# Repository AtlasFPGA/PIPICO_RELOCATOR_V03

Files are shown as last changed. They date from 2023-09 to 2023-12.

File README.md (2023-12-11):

# PIPICO_RELOCATOR_V0

Group ATLAS in Telegram: https://t.me/INICIATIVAATLAS

Agregadas salidas para poder usar módulos I2S Texas Instruments PCM5102A

Visionado del ajuste de pares diferenciales:
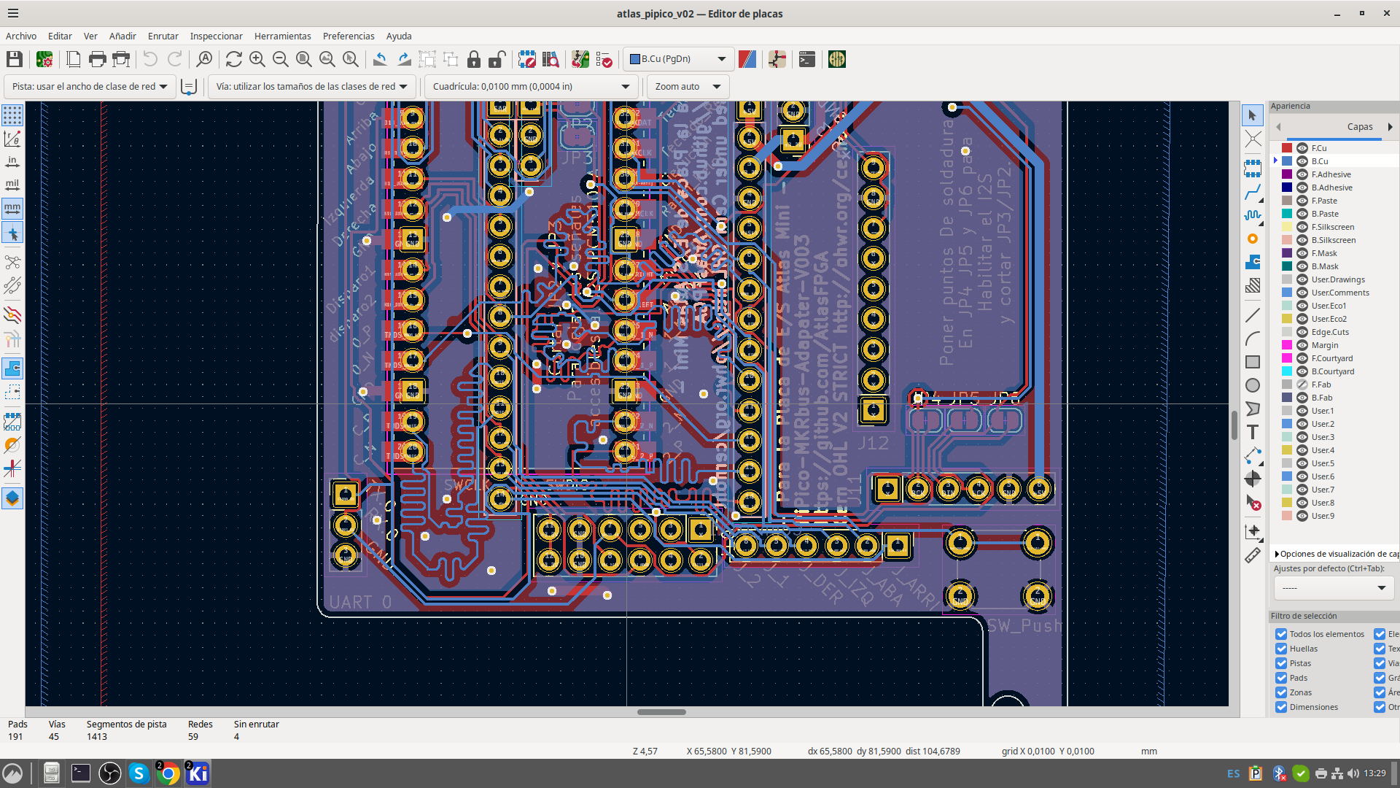
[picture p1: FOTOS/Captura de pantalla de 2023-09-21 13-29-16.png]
ajustar distancia pares diferenciales


Modificaciones sobre el recolocador PI-PICO que ha realizado Carlos Palmero, con el objetivo de que quede más centrada la placa en la versión de coste reducido de ATLAS, es decir "¡la roja!"
Marcando el uso de un módulo I2S de bajo costo como es el Texas Instruments PCM5102A, y posiblemente en el futuro un micrófono capacitivo I2S.

El proyecto pone a disposición los ficheros necesarios del paquete de desarrollo KICAD.
Se han calculado todas las pistas de los pares diferenciales y en este modelo se han ajustado por completo, desde la medición de la longitud de las pistas en la placa "¡la roja!" para que la distancia de los pares coincidan en todas las pistas.

Vistas en 3D del montaje, se puede ver que he dejado el orificio para ajustar la posición de la placa, y que se ha recortado la zona del bus de 40 pines.

### Vista 1 Tridimensional:
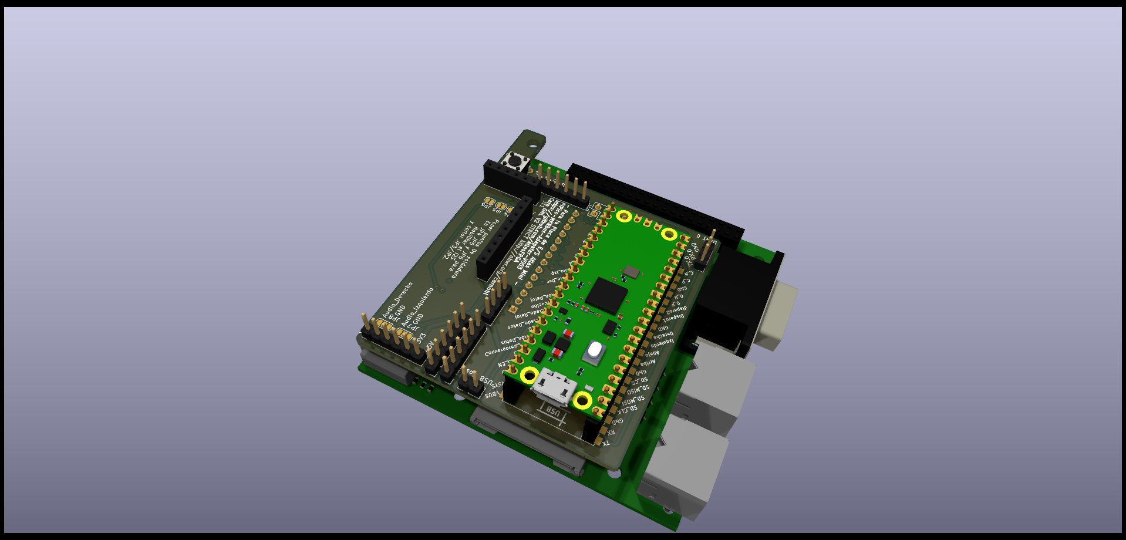
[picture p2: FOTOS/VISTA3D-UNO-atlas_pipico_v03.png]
Vista tridimensional 1


### Vista 2 Tridimensional:
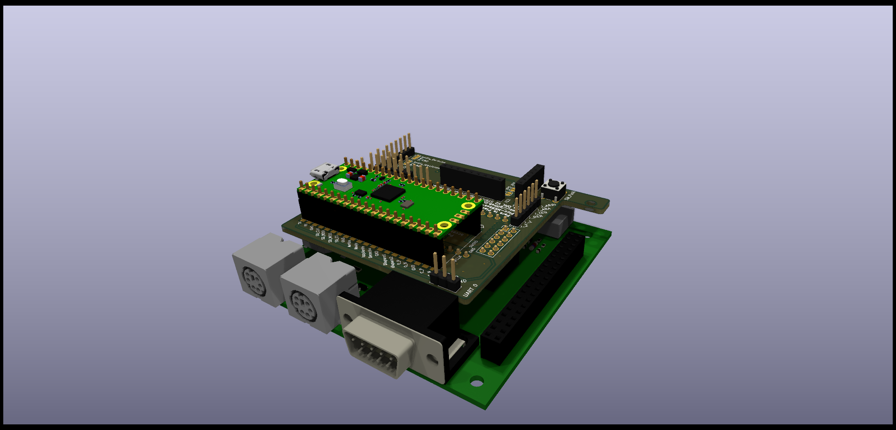
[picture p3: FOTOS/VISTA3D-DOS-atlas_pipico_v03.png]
Vista tridimensional 2


### Vista 3 Tridimensional:
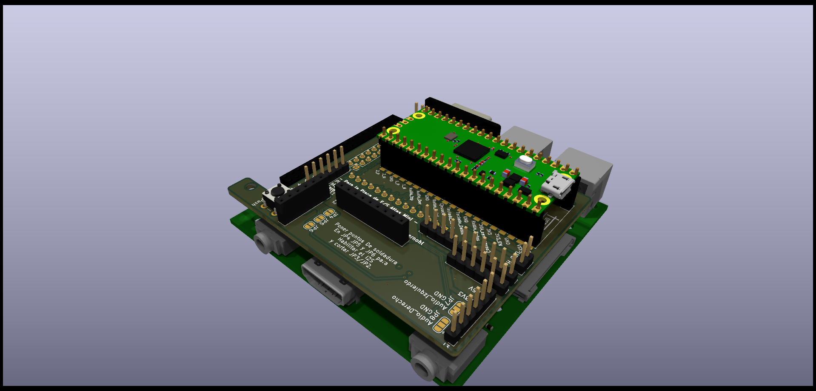
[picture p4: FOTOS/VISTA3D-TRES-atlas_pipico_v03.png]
Vista tridimensional 3


Licencia:
CERN OHL V2 STRICT
https://ohwr.org/cern_ohl_s_v2.txt

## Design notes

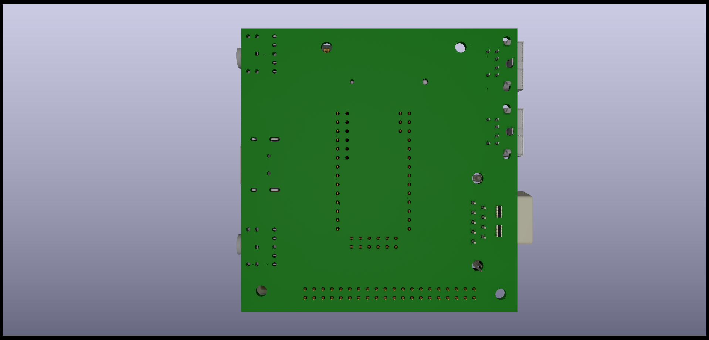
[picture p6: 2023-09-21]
FOTOS/Inferior-atlas_pipico_v03.png

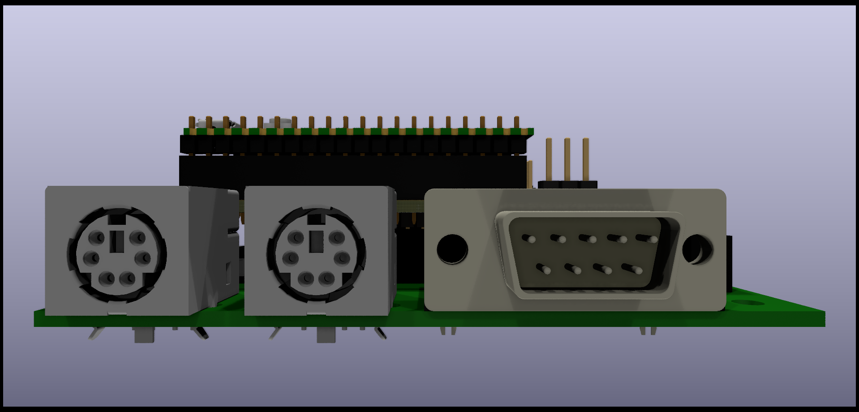
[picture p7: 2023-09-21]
FOTOS/Izquierda-atlas_pipico_v03.png

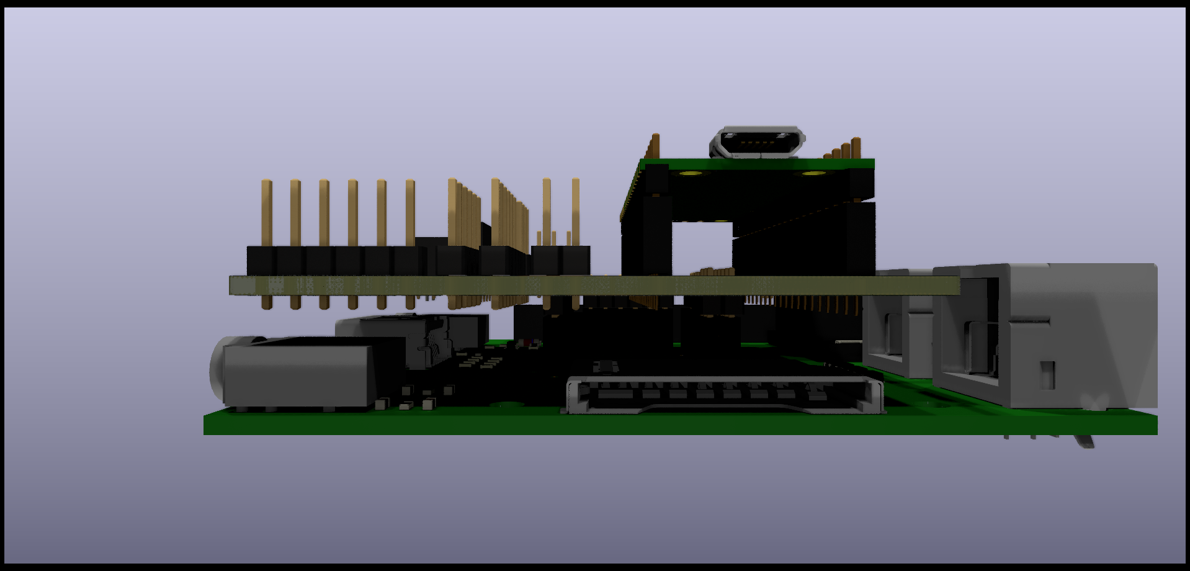
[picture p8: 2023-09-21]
FOTOS/Trasera-atlas_pipico_v03.png

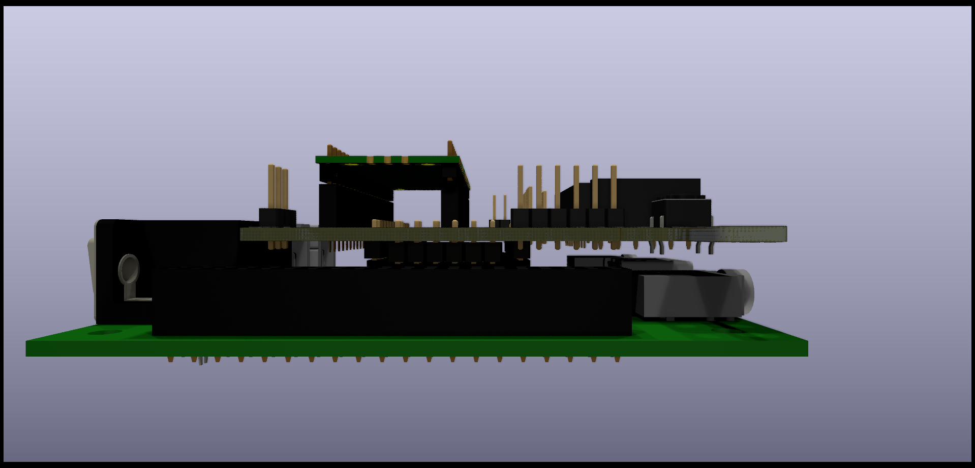
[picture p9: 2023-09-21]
FOTOS/Frontal-atlas_pipico_v03.png

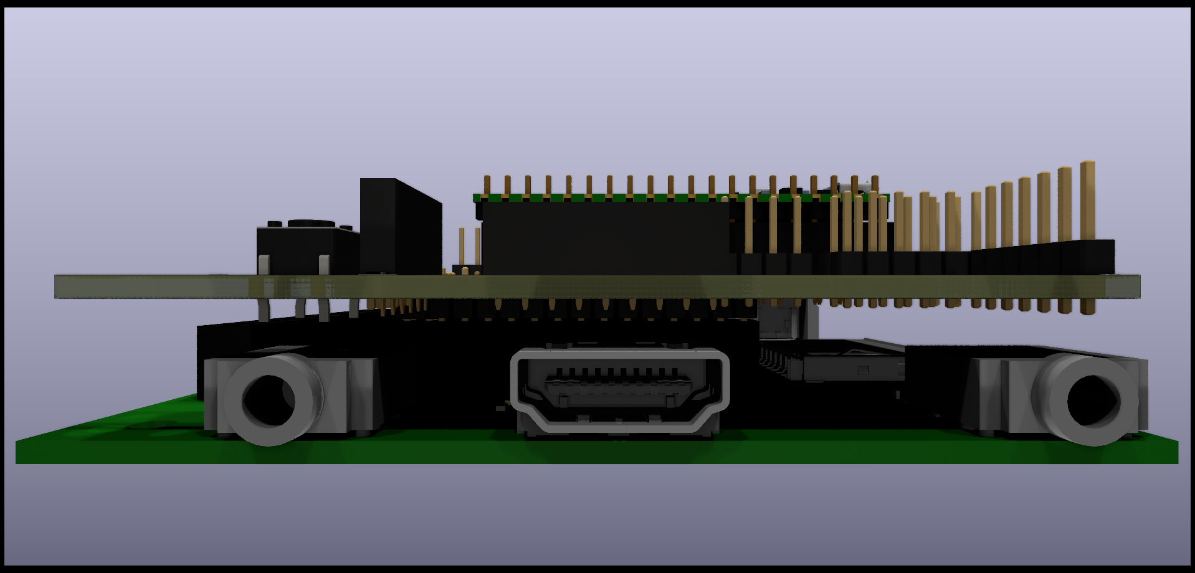
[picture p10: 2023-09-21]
FOTOS/Derecha-atlas_pipico_v03.png

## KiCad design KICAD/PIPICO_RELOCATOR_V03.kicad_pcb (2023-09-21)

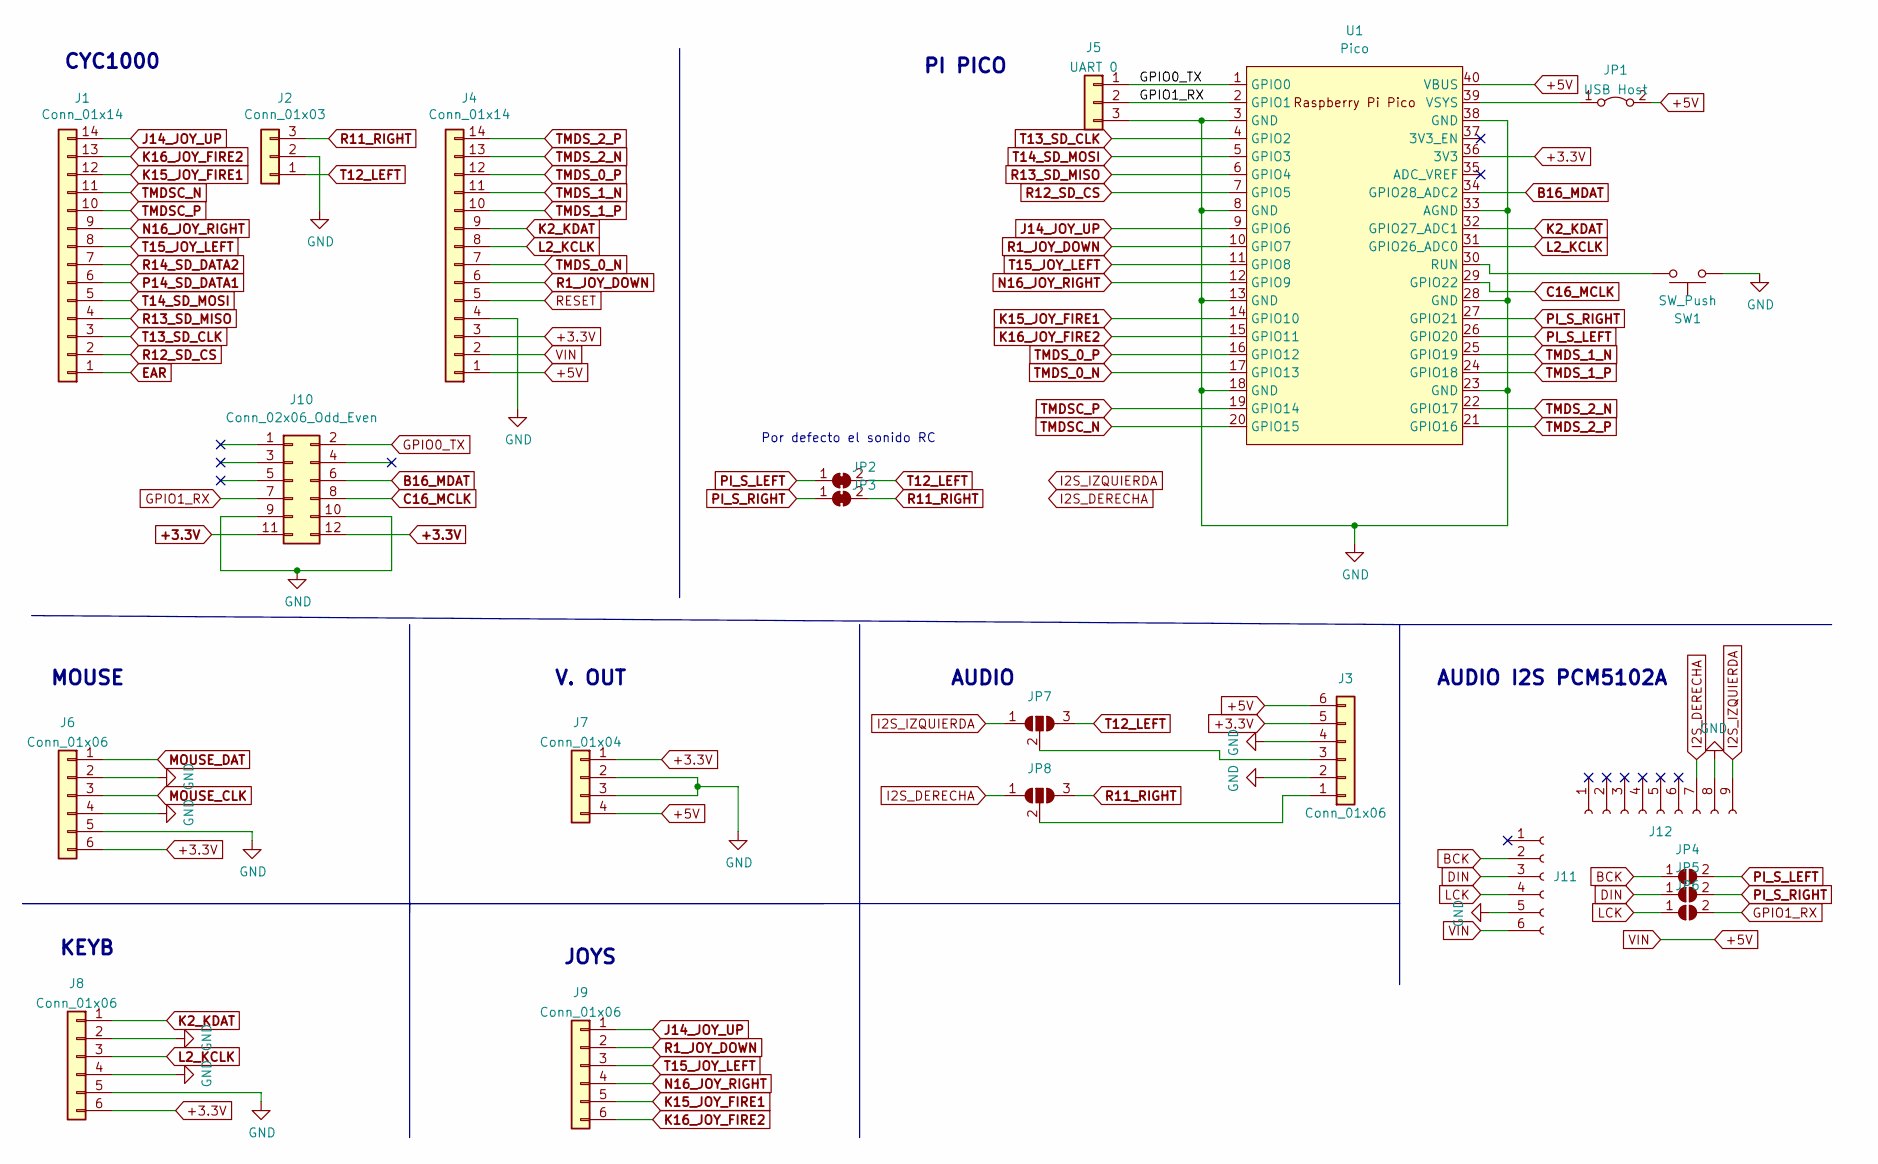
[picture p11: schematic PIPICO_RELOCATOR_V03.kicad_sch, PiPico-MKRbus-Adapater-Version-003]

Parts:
J1, J4: Conn_01x14; PinHeader_1x14_P2.54mm_Vertical
J2: Conn_01x03; PinHeader_1x03_P2.54mm_Vertical
J3, J6, J8, J9: Conn_01x06; PinHeader_1x06_P2.54mm_Vertical
J5: UART 0; PinHeader_1x03_P2.54mm_Vertical
J7: Conn_01x04; PinHeader_1x04_P2.54mm_Vertical
J10: Conn_02x06_Odd_Even; PinHeader_2x06_P2.54mm_Vertical
J11: Conn_01x06_Female; PinSocket_1x06_P2.54mm_Vertical
J12: Conn_01x09_Female; PinSocket_1x09_P2.54mm_Vertical
JP1: USB Host; PinHeader_1x02_P2.54mm_Vertical
JP2, JP3: SolderJumper_2_Bridged; SolderJumper-2_P1.3mm_Bridged2Bar_RoundedPad1.0x1.5mm
JP4, JP5, JP6: SolderJumper_2_Open; SolderJumper-2_P1.3mm_Open_RoundedPad1.0x1.5mm
JP7, JP8: SolderJumper_3_Open; SolderJumper-3_P1.3mm_Open_RoundedPad1.0x1.5mm
SW1: SW_Push; SW_PUSH_6mm
U1: Pico; RPi_Pico_SMD_TH

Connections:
+3.3V: J3.5, J4.3, J6.6, J7.1, J8.6, J10.11, J10.12, U1.36 (3V3)
+5V: J3.6, J4.1, J4.2, J7.4, J11.6, JP1.2 (B), U1.40 (VBUS)
B16_MDAT: J10.6, U1.34 (GPIO28_ADC2)
BCK: J11.2, JP4.1 (A)
C16_MCLK: J10.8, U1.29 (GPIO22)
DIN: J11.3, JP5.1 (A)
EAR: J1.1
GND: J2.2, J3.2, J3.4, J4.4, J5.3, J6.2, J6.4, J6.5, J7.2, J7.3, J8.2, J8.4, J8.5, J10.9, J10.10, J11.5, J12.8, SW1.2, U1.3 (GND), U1.8 (GND), U1.13 (GND), U1.18 (GND), U1.23 (GND), U1.28 (GND), U1.33 (AGND), U1.38 (GND)
GPIO0_TX: J5.1, J10.2, U1.1 (GPIO0)
GPIO1_RX: J5.2, J10.7, JP6.2 (B), U1.2 (GPIO1)
I2S_DERECHA: J12.7, JP8.1 (A)
I2S_IZQUIERDA: J12.9, JP7.1 (A)
J14_JOY_UP: J1.14, J9.1, U1.9 (GPIO6)
K2_KDAT: J4.9, J8.1, U1.32 (GPIO27_ADC1)
K15_JOY_FIRE1: J1.12, J9.5, U1.14 (GPIO10)
K16_JOY_FIRE2: J1.13, J9.6, U1.15 (GPIO11)
L2_KCLK: J4.8, J8.3, U1.31 (GPIO26_ADC0)
LCK: J11.4, JP6.1 (A)
MOUSE_CLK: J6.3
MOUSE_DAT: J6.1
N16_JOY_RIGHT: J1.9, J9.4, U1.12 (GPIO9)
unnamed: J3.1, JP8.2 (C)
unnamed: J3.3, JP7.2 (C)
unnamed: JP1.1 (A), U1.39 (VSYS)
unnamed: SW1.1, U1.30 (RUN)
P14_SD_DATA1: J1.6
PI_S_LEFT: JP2.1 (A), JP4.2 (B), U1.26 (GPIO20)
PI_S_RIGHT: JP3.1 (A), JP5.2 (B), U1.27 (GPIO21)
R1_JOY_DOWN: J4.6, J9.2, U1.10 (GPIO7)
R11_RIGHT: J2.3, JP3.2 (B), JP8.3 (B)
R12_SD_CS: J1.2, U1.7 (GPIO5)
R13_SD_MISO: J1.4, U1.6 (GPIO4)
R14_SD_DATA2: J1.7
RESET: J4.5
T12_LEFT: J2.1, JP2.2 (B), JP7.3 (B)
T13_SD_CLK: J1.3, U1.4 (GPIO2)
T14_SD_MOSI: J1.5, U1.5 (GPIO3)
T15_JOY_LEFT: J1.8, J9.3, U1.11 (GPIO8)
TMDSC_N: J1.11, U1.20 (GPIO15)
TMDSC_P: J1.10, U1.19 (GPIO14)
TMDS_0_N: J4.7, U1.17 (GPIO13)
TMDS_0_P: J4.12, U1.16 (GPIO12)
TMDS_1_N: J4.11, U1.25 (GPIO19)
TMDS_1_P: J4.10, U1.24 (GPIO18)
TMDS_2_N: J4.13, U1.22 (GPIO17)
TMDS_2_P: J4.14, U1.21 (GPIO16)

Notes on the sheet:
MOUSE
CYC1000
AUDIO
KEYB
JOYS
PI PICO
Por defecto el sonido RC
AUDIO I2S PCM5102A
V. OUT

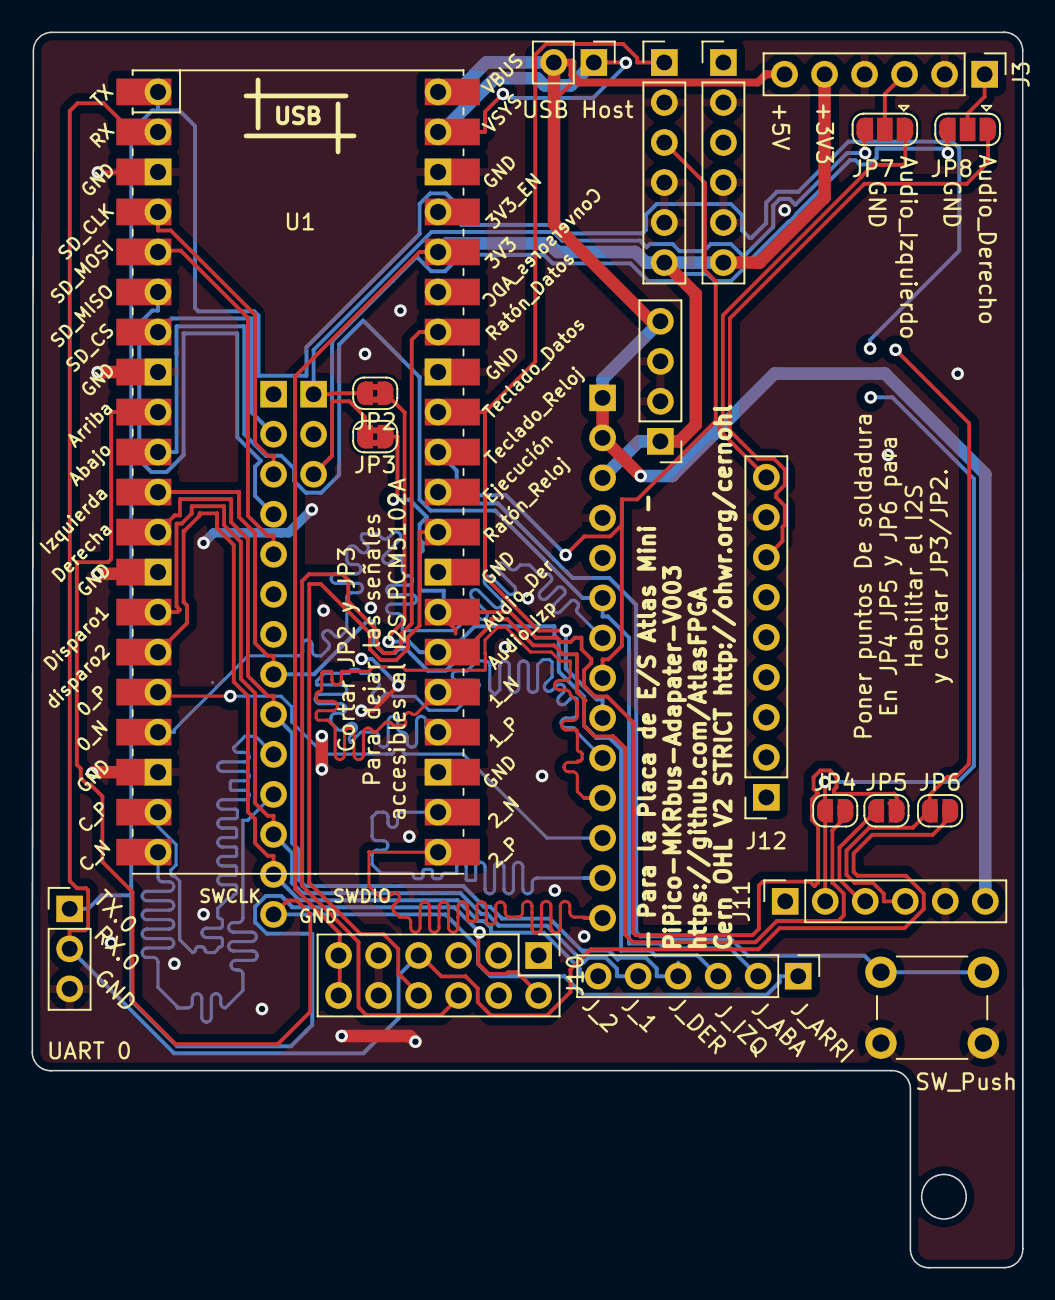
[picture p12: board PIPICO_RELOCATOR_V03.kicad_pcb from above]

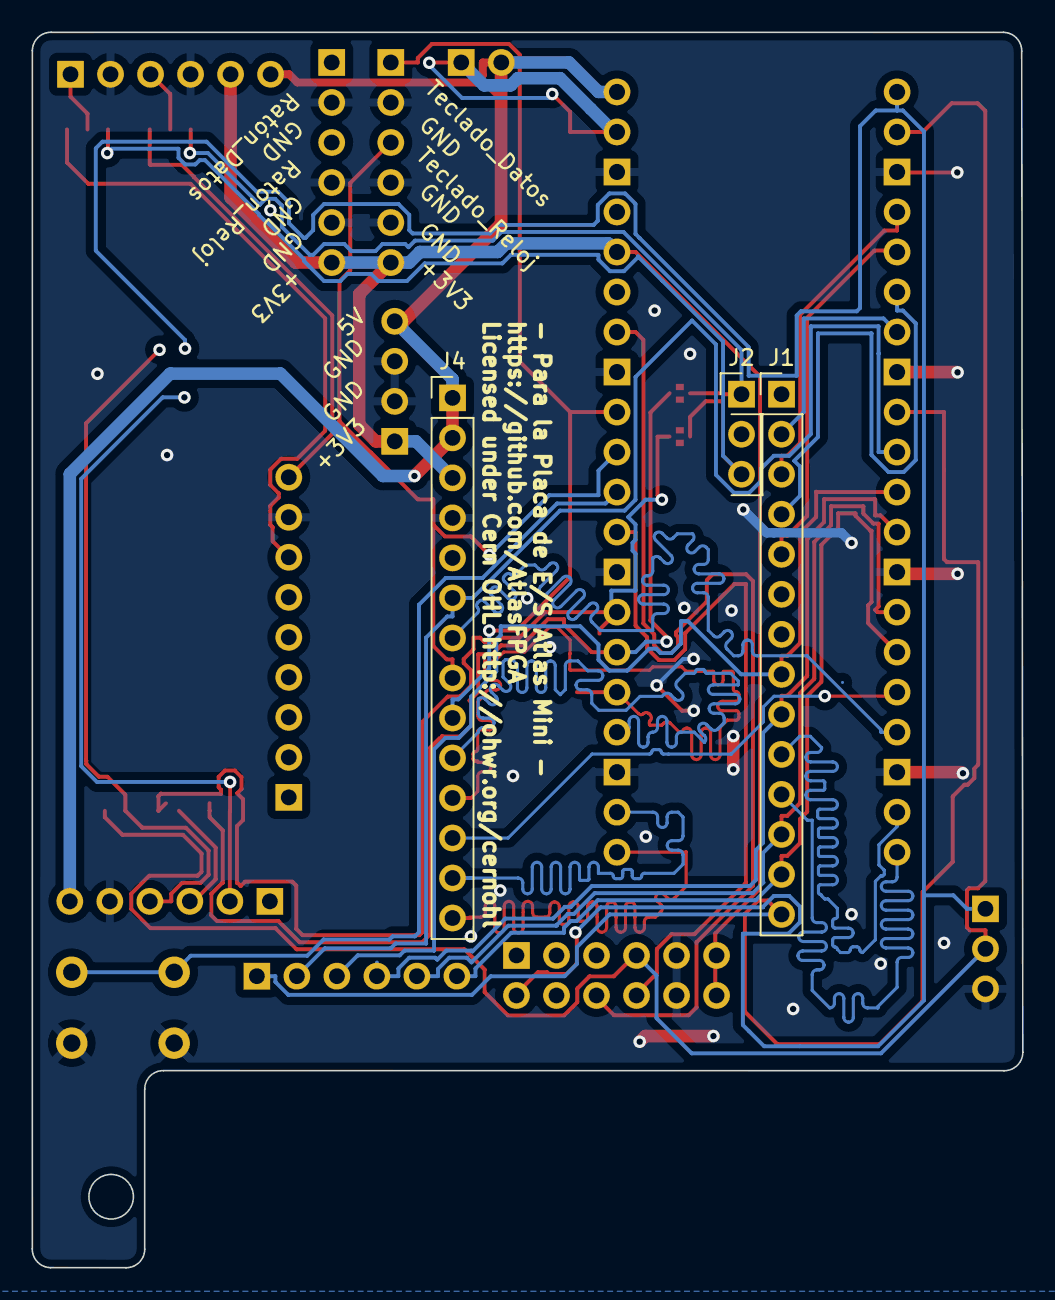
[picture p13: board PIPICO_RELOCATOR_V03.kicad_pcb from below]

Board: 2 copper layers, 62.9 x 78.4 mm, 22 parts (3 on the bottom side), 40 nets.

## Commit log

2023-09-21 Primera información sobre la placa V03 de PIPICO README.md
2023-09-21 Pantallazos del recolocador PIPICO con ajuste de lineas de pares diferenciales
2023-09-21 Agregar fotos del desarrollo con i2s para pi-pico README.md
2023-09-21 Cambio en los incrustados de imágenes README.md
2023-09-21 Recolocador en su tercera versión ajustado a las dimensiones de la ATLAS MINI
    [PIPICO_RELOCATOR_V03.dsn, PIPICO_RELOCATOR_V03.kicad_pcb, PIPICO_RELOCATOR_V03.kicad_sch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]
2023-09-21 subir pantallazo de la visión tridimensional donde aparece la SD y el vídeo digital.
2023-09-21 Agregar el tipo de licencia README.md

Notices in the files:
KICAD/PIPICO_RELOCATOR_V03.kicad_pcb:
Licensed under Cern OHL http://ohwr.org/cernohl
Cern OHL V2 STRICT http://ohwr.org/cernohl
